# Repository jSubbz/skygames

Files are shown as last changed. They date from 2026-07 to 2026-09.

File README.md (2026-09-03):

# Skygames

Hide and seek played with an FPV drone. A puck gets hidden somewhere in the play
area, the pilot flies out to find it, and a handheld controller gets warmer or
colder (more frequent beeps/less frequent beeps) as the drone closes in.

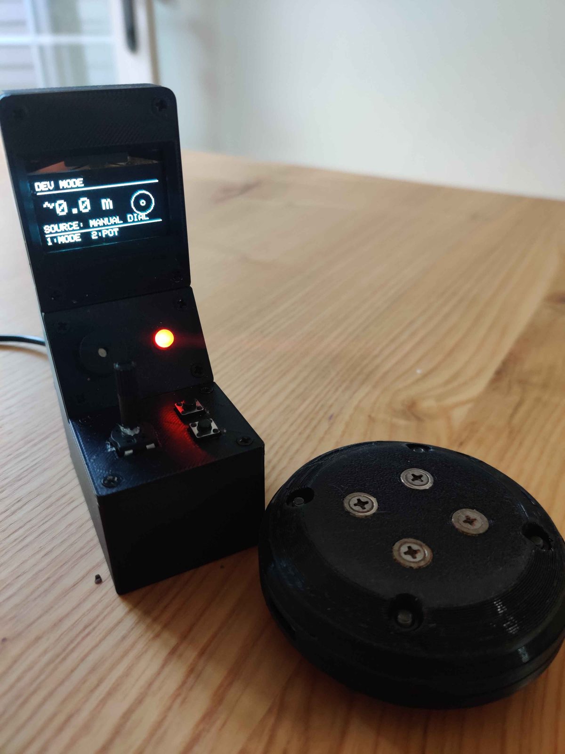
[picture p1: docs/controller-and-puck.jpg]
The controller and the puck. The controller is a printed hinged case with an OLED reading "DEV MODE", a lit red LED, two buttons and a dial; the puck is a black printed disc.


## How the game works

Three boards, one job each.

The **puck** broadcasts a small beacon packet about ten times a second. That is
its only job - it never listens for anything.

The **drone** is the seeker. It hears the beacon, reads the signal strength of
each packet as it arrives, filters it, and buckets the result into NEAR / MID /
FAR / LOST. It relays that zone to the controller about ten times a second.

The **controller** plays the zone back to the pilot on a buzzer and an RGB LED.
No RSSI math happens there.

The sensing sits on the drone on purpose: the drone is the one flying around the
puck, so it has to be the one sensing proximity. A controller sitting still on
the ground would be measuring the pilot's distance instead, which is not the
number anyone wants.

## Signal strength, not GPS

The first design has the puck and the drone both reporting GPS positions, with
the controller working out the distance between them. It does not hold up
indoors: the M10Q cannot keep a fix inside a building, and the system has to
work indoors and out. Signal strength needs no satellites. It is noisy, but it
moves in the right direction, and that is enough for hot-and-cold.

GPS keeps one job - **follow home**, where the drone measures against its own
launch point instead of against the puck. That distance is big enough for GPS to
be good at it, and it is an outdoor feature anyway.

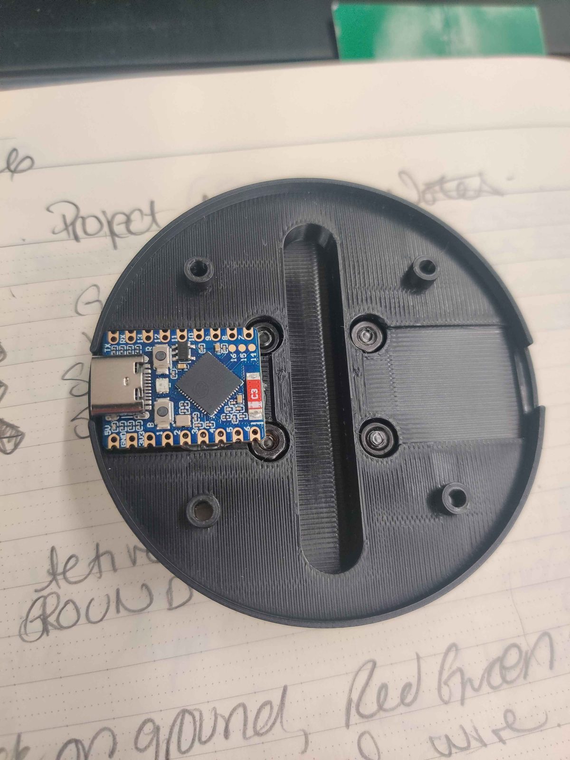
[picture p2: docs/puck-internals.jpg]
The inside of the puck: a printed disc with an ESP32-C3 board screwed to it, sitting on a page of wiring notes.


## Feedback

The buzzer is an active one, so it has a fixed pitch and can only be switched on
and off - it cannot be pitch-shifted by driving the pin at different
frequencies. Proximity is carried by beep rate instead: faster clicks as you get
closer. It runs through PWM rather than a plain digital write so the volume can
be turned down, which it needed.

The RGB LED is PWM-driven too, so colour is a real gradient rather than a few
fixed hues: green close, red far, blending through yellow between, off when the
signal is lost. It blinks in sync with the buzzer.

Two buttons. **Mode** toggles between follow-puck and follow-home. **Pot
toggle** switches the potentiometer dial in and out of the loop - the dial is a
bench override that feeds a manual distance in place of live sensing.

## Repository layout

```
src/controller/        the handheld unit - display, buzzer, RGB LED, buttons
src/esp_now_gps_tx/    the drone - GPS fix, RSSI sensing, relays both
src/puck_gps_tx/       the puck - beacon broadcaster
src/experiments/       bench sketches, one per component (see its README)
models/                FreeCAD enclosures for the puck and the controller
docs/                  photos
```

Those three sketches stand in for eleven. Every component gets proved on its own
first - a sketch that only blinks an LED over the radio, one that only parses
GPS, one that only drives the screen - and the working parts fold into three
programs that talk to each other. The originals stay in `src/experiments/`, both
as a record and because several are still the quickest way to test a board you
have just soldered.

`puck_gps_tx` keeps its name from when the puck still carried GPS. The name is
wrong, but the history is easier to follow with it left alone.

## Hardware

| Part | Board |
|---|---|
| Controller | ESP32-C6 Pico |
| Drone | ESP32-C3 |
| Puck | ESP32-C3 |

| Peripheral | Notes |
|---|---|
| SH1106 OLED | I2C, driven through Adafruit GFX and SH110X |
| M10Q GPS module | UART, parsed with TinyGPS++ |
| Active piezo buzzer | Fixed pitch, so feedback is by rate |
| Common-cathode RGB LED | PWM, continuous green-to-red gradient |
| Momentary pushbuttons | Mode, and the dial override |
| Potentiometer | Bench override for manual distance |
| 18650 cell + TP4056 | Power and USB-C charging |

Controller wiring, confirmed against the built unit:

```
OLED (I2C)        SDA 22, SCL 23
Buttons           mode 2, pot toggle 3
Buzzer            18
RGB LED           19 / 20 / 21
Potentiometer     0
```

On the drone, the GPS module's TX line goes to GPIO20. It is a passive tap - the
sketch passes -1 for its own TX pin, so it can never drive the wire it is
reading.

## Flashing

Arduino IDE with the `esp32` boards package by Espressif, version 3.x. Pick
**ESP32C6 Dev Module** for the controller and **ESP32C3 Dev Module** for the
drone and the puck. Enable *USB CDC On Boot* on all three - these boards have no
USB-to-serial chip, so that is what makes Serial work over the native USB-C
port.

Libraries: **TinyGPSPlus** by Mikal Hart (not the older `TinyGPS`, which has a
different API), **Adafruit GFX**, **Adafruit SH110X**.

All three boards need to be locked to the same WiFi channel - see
`WIFI_CHANNEL` in each sketch. RSSI readings only compare within a channel, and
the link is only reliable when the radios agree on one.

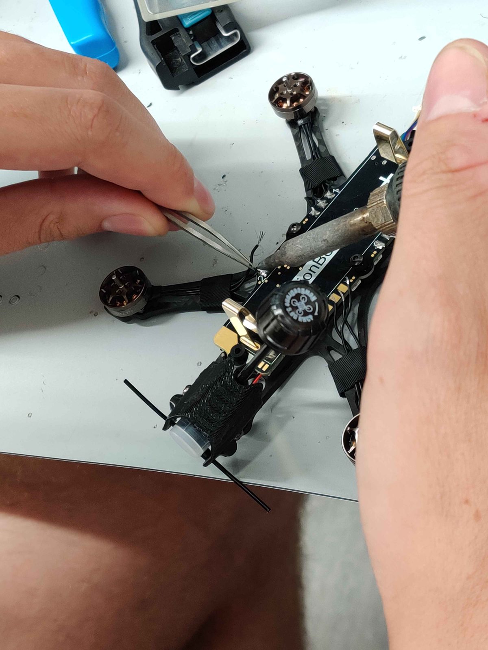
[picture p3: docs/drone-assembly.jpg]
A drone frame being soldered by hand, motors and wiring visible.


## Enclosures

`models/` holds the FreeCAD sources for the puck and controller housings. No
mesh exports yet, so printing one means opening FreeCAD for now.

## Known rough edges

The boards address each other by **broadcast**, not by paired MAC. It works with
no setup, and it also means a board picks up beacons from any other Skygames
puck in range. Each sketch prints its own MAC on boot, so swapping in real peer
addresses is a small change when it matters.

The controller's **screen is a placeholder** - a plain status readout, not a
designed interface. The "set puck" screen in `src/experiments/ui_test` is where
that was heading.

The **potentiometer has a worn track** and jumps on its own occasionally - it
came out of a school kit and has had a previous life. That is why there is a
button to shut the dial out of the loop entirely.

## Next

**More game modes** - capture the flag, push the cart - on the same telemetry
and RSSI foundation. Game logic is centralised on the controller, so a new mode
needs no drone firmware change. That is most of why it is built that way.

**A drone-agnostic mount** around the 1S/18650 power system consumer
micro-drones already use, so the electronics bolt onto a drone somebody already
owns instead of needing a custom build.

**Better-sounding audio cues** for players, so a bare buzzer is not the only
thing to listen to.

**Peer MACs and a designed screen**, both from the rough edges above.

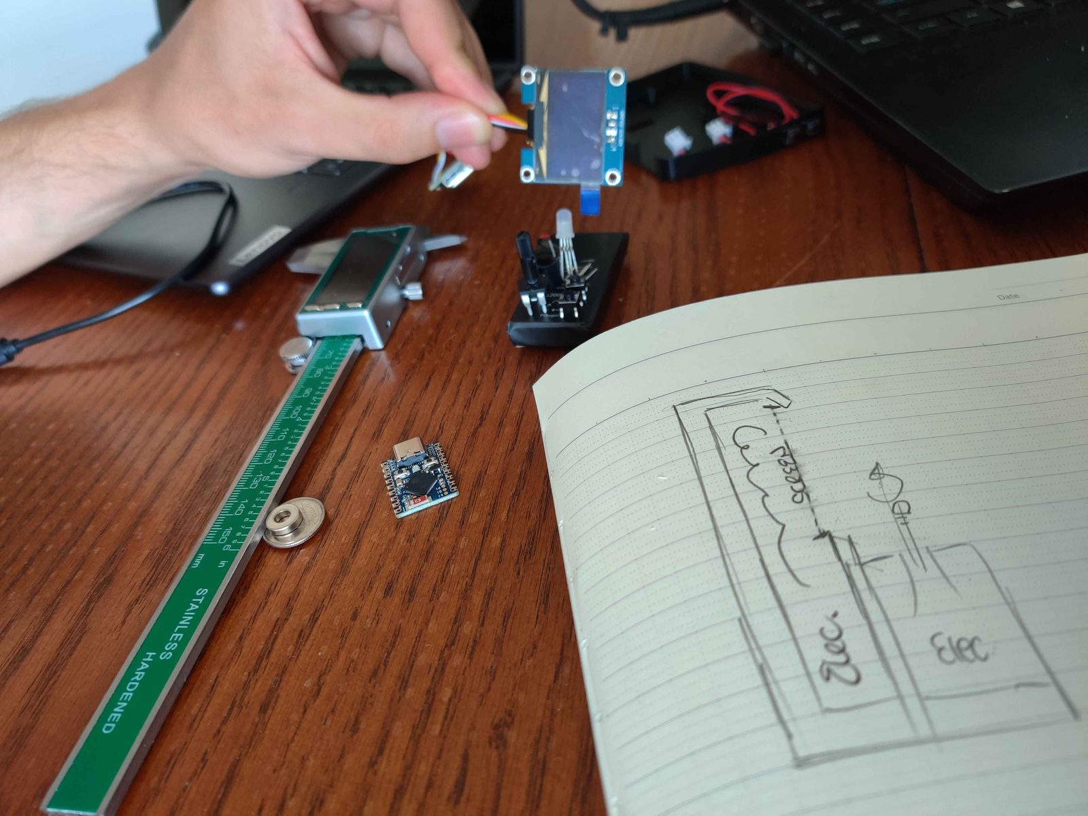
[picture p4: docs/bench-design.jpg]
Early bench work: an OLED, an encoder and a bare ESP32 board on a desk beside a notebook sketch of the controller.


## Credits

Built with Brayden ([@braybuch](https://github.com/braybuch)) for ENL 4003.
Brayden handled hardware selection, bench testing and enclosure work, and wrote
the original proximity finder the whole signal-strength approach comes out of.

## Licence

MIT - see [LICENSE](LICENSE).

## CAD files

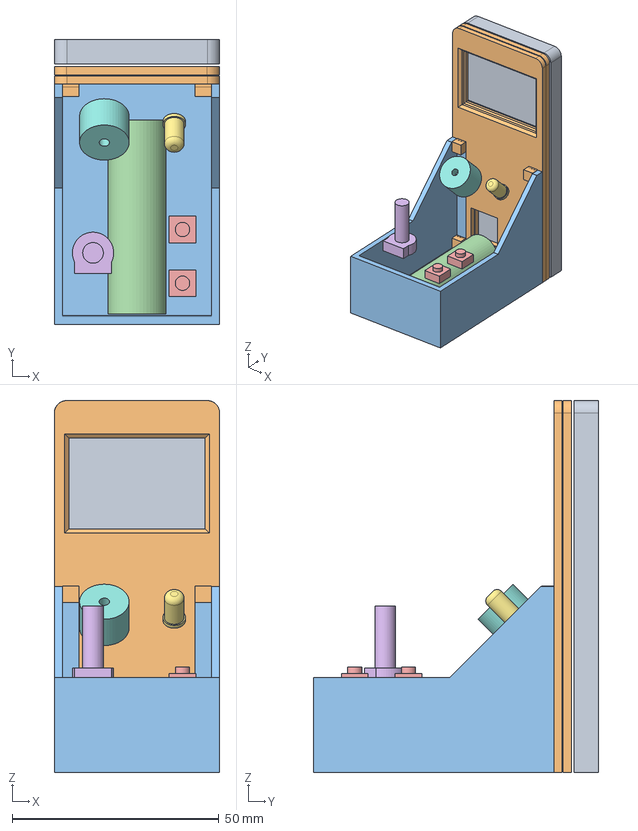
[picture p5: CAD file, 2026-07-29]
models/controller.FCStd
40.0 x 69.0 x 90.0 mm
Upper-Back
Upper-Front x 2
Lower-Bottom x 2
AA
Button x 2
Knob
LED
Beeper
1.3-inch-llc-V3.001

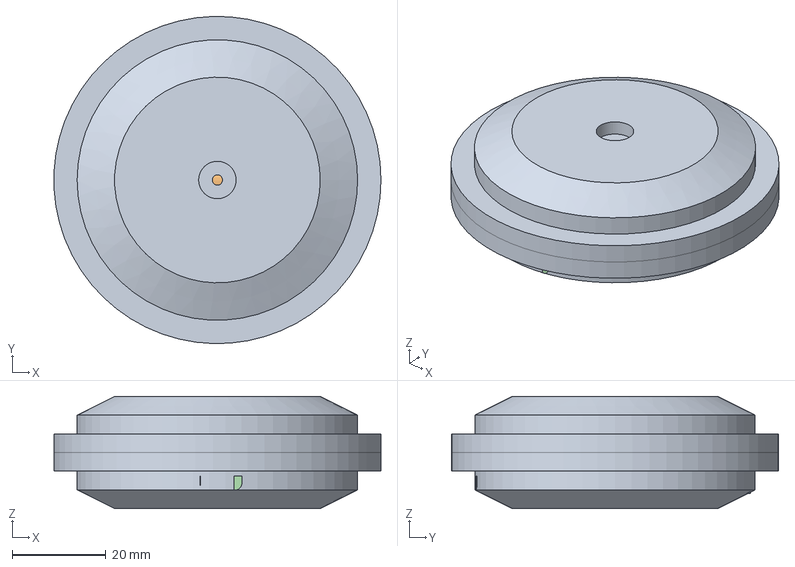
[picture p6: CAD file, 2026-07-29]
models/puck.FCStd
70.0 x 70.0 x 24.0 mm
puck x 2
AAA battery
ESP32S3 Zero
LX-LBC3

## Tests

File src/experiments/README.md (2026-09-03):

# Experiments

Bench sketches from building the system, each one written to prove a single
component or idea on its own before it was allowed near the real thing. None of
them are part of the game; they are kept because they are how the three sketches
in `src/` came to work, and because several are still the quickest way to test a
board you have just soldered.

| Sketch | What it proved |
|---|---|
| `mac-finder` | Prints a board's MAC address. Needed before ESP-NOW can address a specific peer. |
| `tesst` | Blinks the onboard LED. The first thing to run on a board you are not sure is alive. |
| `blinky_tx` / `blinky_rx` | Smallest possible ESP-NOW link: one board makes the other's LED blink. Proves the radio pairing before any payload matters. |
| `hardwaretest` | ESP32-C6 Pico bring-up - every pin on the controller exercised in one sketch. |
| `gps_parse_test` | Reads the GPS module over UART and parses it with TinyGPS++. Passive listener, no radio. |
| `esp_now_display_tx` / `esp_now_display_rx` | Sends an invented, slowly drifting GPS fix to an SH1106 OLED. Let the display and the message format be tested with no GPS lock and no second location. |
| `esp_now_gps_rx` | The display receiver wired to real GPS data rather than the mock. |
| `esp_now_proximity_finder` | Brayden's two-role prototype: one board broadcasts a beacon, the other reads RSSI, filters it and buckets it into NEAR / MID / FAR / LOST. This is the sketch the whole RSSI approach came out of, and both `puck_gps_tx` and the drone's sensing are descended from it. |
| `ui_test` | Standalone rig for the "Set Puck" screen - OLED, two buttons and a rotary encoder, with no radio attached. |

## Flashing any of them

Arduino IDE with the `esp32` boards package by Espressif, version 3.x. Board
depends on the sketch - the ESP32-S3 Zero sketches want **ESP32S3 Dev Module**
with *USB CDC On Boot* enabled, which is what makes Serial work over the native
USB-C port. Individual sketches note their own wiring in the header comment.

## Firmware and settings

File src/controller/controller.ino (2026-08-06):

/*
 * Controller / Receiver - consolidated draft (v4)
 * -------------------------------------------------
 * Replaces the separate blinky_rx / esp_now_display_rx / esp_now_gps_rx
 * drafts with one sketch.
 *
 * Architecture (as of this draft):
 *   Puck  --beacon_t, ~10x/sec-->  Drone
 *   Drone --filters RSSI, classifies NEAR/MID/FAR/LOST zone (same
 *           logic as esp_now_proximity_finder.ino's SEEKER role) -->
 *   Drone --proximity_report_t, ~10x/sec-->  Controller (this board)
 *   Controller drives buzzer/RGB LED off the zone the drone relays. No
 *   RSSI math happens here - the drone is the one flying around the
 *   puck, so it has to be the one sensing proximity; the controller
 *   just plays the result back to the operator.
 *
 *   Drone --struct_message (GPS), ~1x/sec--> Controller, for the
 *   separate FOLLOW HOME feature (drone <-> its own first fix, no
 *   controller GPS). Puck no longer sends GPS - drone<->puck finding
 *   is RSSI-only.
 *
 * Controls (2026-08-06 - button roles changed from earlier drafts):
 *   - Button 1 (MODE): toggles between FOLLOW PUCK and FOLLOW HOME each
 *     press - no longer two separate "set to X" buttons.
 *   - Button 2 (POT TOGGLE): enables/disables the potentiometer dial
 *     override entirely. Added because the dial's known worn-track
 *     jumpiness (see notes further down) could occasionally trip
 *     dialOverrideActive on its own and never let go of live sensing -
 *     this gives a hard way to shut the dial out of the loop while
 *     testing the real puck/drone system.
 *   - Potentiometer dial (only listened to while pot override is
 *     enabled): dev/test override. Turning it feeds a manual distance
 *     into the buzzer/LED instead of live sensing; reverts to live data
 *     automatically 5s after you stop turning it.
 *
 * Screen content is still open (per team discussion) - updateDisplay()
 * below is a plain status readout, not a locked-in UI design. Treat it
 * as a placeholder to swap out once the "SET PUCK" screen concept
 * (ui_test.ino) is settled.
 *
 * WIRE PROTOCOL - three message types travel over ESP-NOW to this board:
 * ------------------------------------------------------------------
 *   struct_message (GPS) - sent ~1x/sec by esp_now_gps_tx.ino (drone
 *   only now). Must match field-for-field:
 *
 *     typedef struct struct_message {
 *       uint8_t deviceId;  // DEVICE_DRONE (0) or DEVICE_PUCK (1)
 *       bool fixValid;
 *       double lat;
 *       double lon;
 *       uint8_t sats;
 *     } struct_message;
 *
 *   proximity_report_t (RSSI relay) - sent ~10x/sec by the drone
 *   (esp_now_gps_tx.ino), which does its own RSSI filtering/zone
 *   classification against the puck's beacon. Must match exactly:
 *
 *     typedef struct { float rssi; uint8_t zone; } proximity_report_t;
 *     // zone: 0=NEAR, 1=MID, 2=FAR, 3=LOST
 *
 * The puck's beacon_t (see puck_gps_tx.ino / esp_now_proximity_finder.ino)
 * is NOT received here directly anymore - the drone is the one that
 * listens for it.
 *
 * All radios (controller, drone, puck) should lock to the same fixed
 * WiFi channel (see WIFI_CHANNEL below) for reliable reception.
 *
 * PIN CONFIG - confirmed against real controller wiring (2026-08-05).
 * ------------------------------------------------------------
 * Matches hardwaretest.ino, which is flashed on this board and fully
 * working: OLED on 22/23, buttons on 2/3, buzzer on 18, RGB LED
 * (common cathode) on 19/20/21, potentiometer wiper on GPIO0. The
 * earlier v3 draft's pins (I2C 6/7, buttons 4/5, rotary encoder
 * 2/3/1) were copied from ui_test.ino's separate bench rig and did
 * not match this board - replaced below.
 *
 * BUZZER - confirmed genuinely active (2026-08-05), not a passive
 * piezo. An active buzzer has its own fixed-pitch oscillator and can
 * only be switched on/off - it cannot be pitch-shifted by driving the
 * pin at different frequencies. So zone/distance feedback below is
 * conveyed by beep RATE (how fast it clicks) instead of pitch. Driven
 * via LEDC PWM rather than a plain digitalWrite so BUZZER_VOLUME_PERCENT
 * can turn the volume down (2026-08-05 - full HIGH/LOW drive was too loud).
 *
 * RGB LED (2026-08-06) - also PWM-driven now (not plain on/off), so
 * color is a genuine continuous gradient instead of a handful of fixed
 * hues: green = close, red = far, blending through yellow in between.
 * off = lost/no signal. (Earlier draft had this backwards - red=close -
 * flipped per team direction.) Still blinks in sync with the buzzer's
 * on/off click.
 */

#include <Wire.h>
#include <Adafruit_GFX.h>
#include <Adafruit_SH110X.h>
#include <WiFi.h>
#include <esp_now.h>
#include <esp_wifi.h>
#include <math.h>

// ---- Pin configuration (matches hardwaretest.ino / real wiring) ----
#define I2C_SDA 22                   // OLED SDA
#define I2C_SCL 23                   // OLED SCL
#define POT_PIN 0                    // potentiometer wiper - dev/test dial
#define BUTTON_MODE_PIN 2            // = hardwaretest.ino's BUTTON1_PIN - toggles FOLLOW PUCK/HOME
#define BUTTON_POT_TOGGLE_PIN 3      // = hardwaretest.ino's BUTTON2_PIN - enables/disables the dial
#define BUZZER_PIN 18                // active buzzer - on/off only, no pitch control
#define LED_R 19                     // RGB LED, common cathode
#define LED_G 20
#define LED_B 21

// ---- OLED config (same as esp_now_gps_rx.ino / ui_test.ino) ----
#define SCREEN_WIDTH 128
#define SCREEN_HEIGHT 64
#define OLED_ADDR 0x3C
#define OLED_RESET -1
// 0 = as-is, 2 = flipped 180 - set to whichever reads right-side up in
// your enclosure (bench video 2026-08-05 showed text upside down at 0).
#define DISPLAY_ROTATION 2
Adafruit_SH1106G display(SCREEN_WIDTH, SCREEN_HEIGHT, &Wire, OLED_RESET);

// ---- Radio config - must match esp_now_gps_tx.ino / puck_gps_tx.ino ----
#define WIFI_CHANNEL 1
const uint8_t TX_POWER_QUARTER_DBM = 84; // 84 = 21 dBm (max) - keep identical on all radios

// ---- FOLLOW HOME distance -> beep-rate mapping. Tune once real-world
// distances are known. Buzzer is on/off only (see note above), so
// "getting warmer" is conveyed by faster clicking, not higher pitch. ----
const float DIST_MIN_M = 1.0f;             // at or below this: fastest click ("hot")
const float DIST_MAX_M = 100.0f;           // at or above this: slowest click ("cold")
const uint16_t HOME_CLICK_ON_MS = 90;      // click length, constant across the range
const uint16_t HOME_PERIOD_MIN_MS = 150;   // click period when close
const uint16_t HOME_PERIOD_MAX_MS = 1000;  // click period when far

// ---- Buzzer volume, via PWM duty cycle (see header note - active buzzer,
// full HIGH/LOW drive was reported too loud 2026-08-05). Lower duty =
// lower average voltage = quieter, down to some point where a given
// buzzer stops oscillating altogether - stay well above that floor. ----
const int BUZZER_PWM_FREQ_HZ = 20000;      // carrier above hearing range - no PWM whine
const int BUZZER_PWM_RESOLUTION_BITS = 8;  // 0-255 duty steps
const uint8_t BUZZER_VOLUME_PERCENT = 65;  // tune this one knob if it needs to go up/down
const uint8_t BUZZER_DUTY_ON = (uint8_t)(BUZZER_VOLUME_PERCENT * 255 / 100);

// ---- RGB LED gradient config (2026-08-06). Color is continuous now, not
// bucketed - FOLLOW HOME/dial reuse DIST_MIN_M/DIST_MAX_M directly as the
// gradient's near/far ends. FOLLOW PUCK doesn't get a meters value from
// the drone, so it mirrors the RSSI thresholds instead (cosmetic only -
// not wire-protocol critical, but keep roughly in sync with
// esp_now_gps_tx.ino's RSSI_NEAR/RSSI_FAR if those get retuned). ----
const float RSSI_NEAR_MIRROR_DBM = -55.0f; // at/stronger than this: full green
const float RSSI_FAR_MIRROR_DBM  = -82.0f; // at/weaker than this: full red

// ---- Manual override (potentiometer) config ----
const int POT_ADC_MIN = 0;
const int POT_ADC_MAX = 4095;                // ESP32 12-bit ADC
const int POT_MOVE_THRESHOLD = 25;           // ignore ADC jitter smaller than this
const float POT_SMOOTHING_ALPHA = 0.25f;     // 0-1, lower = smoother. Without this, raw ADC
                                              // noise fed straight into periodMs every loop and
                                              // made the buzzer crackle instead of click cleanly
                                              // while turning fast (seen in 2026-08-05 bench video)
const float OVERRIDE_DIST_MIN_M = 0.0f;
const float OVERRIDE_DIST_MAX_M = DIST_MAX_M;
const unsigned long DIAL_OVERRIDE_TIMEOUT_MS = 5000; // revert to live sensing this long after last turn

// ---- GPS freshness (drone only, for FOLLOW HOME) ----
const unsigned long GPS_TIMEOUT_MS = 5000;

// ---- Proximity relay freshness (drone's RSSI report, for FOLLOW PUCK) ----
const unsigned long PROXIMITY_REPORT_TIMEOUT_MS = 800;

// =====================================================================
// GPS wire protocol (drone only - see esp_now_gps_tx.ino)
// =====================================================================
enum DeviceId : uint8_t { DEVICE_DRONE = 0, DEVICE_PUCK = 1 };

typedef struct struct_message {
  uint8_t deviceId;
  bool fixValid;
  double lat;
  double lon;
  uint8_t sats;
} struct_message;

struct_message droneMsg = { DEVICE_DRONE, false, 0, 0, 0 };
unsigned long droneLastSeen = 0;

// ---- Home point: captured once from the drone's first valid fix ----
bool homeSet = false;
double homeLat = 0.0;
double homeLon = 0.0;

// =====================================================================
// RSSI proximity relay (drone senses, this board just consumes it)
// =====================================================================
typedef struct {
  float rssi;
  uint8_t zone;
} proximity_report_t;

enum PuckZone { ZONE_NEAR = 0, ZONE_MID = 1, ZONE_FAR = 2, ZONE_LOST = 3 };
const char *zoneNames[] = { "NEAR", "MID", "FAR", "LOST" };

// on/off click timing only - no freq field, since the buzzer can't be
// pitch-shifted. Must still *feel* like the beep feel
// esp_now_proximity_finder.ino uses (rapid when close, slow when far).
struct BeepPattern {
  uint16_t onMs;       // how long the buzzer sounds within each cycle
  uint16_t periodMs;   // full cycle length (on + off); 0 = silent
};
BeepPattern zonePatterns[4] = {
  { 110, 150 },    // NEAR - rapid, almost continuous
  { 120, 400 },    // MID  - moderate beeping
  { 150, 1000 },   // FAR  - slow beeps
  { 0,   0    }    // LOST - silent
};

// PWM intensities (0-255 per channel) now, not on/off bools - lets the
// LED show a real blended color instead of one of 8 fixed hues.
struct RgbColor { uint8_t r, g, b; };
const RgbColor COLOR_OFF = { 0, 0, 0 };

// All struct types live up here, before ANY function definition (even
// ones like gradientColor() right below that don't use these two) - the
// Arduino IDE hoists auto-generated prototypes for every function as one
// block, inserted at the position of the FIRST function definition in the
// file. Whatever that first function ends up being, every type used by
// ANY function's signature has to already be defined above it, or you
// get "does not name a type" (bit us twice now - 2026-08-05, 2026-08-06 -
// each time a new function got added earlier in the file than the last
// one). Keeping every struct in one block up front avoids this for good.
struct AvState {
  BeepPattern pattern;
  RgbColor color;
};

struct DebouncedButton {
  uint8_t pin;
  bool lastReading;
  bool stableState;
  unsigned long lastChangeMs;
  DebouncedButton(uint8_t p) : pin(p), lastReading(HIGH), stableState(HIGH), lastChangeMs(0) {}
};

// t=0 -> full green (close), t=1 -> full red (far), blending through
// yellow at t=0.5. Caller is responsible for mapping their real-world
// value (meters or RSSI) onto this normalized 0..1 range first.
RgbColor gradientColor(float t) {
  t = constrain(t, 0.0f, 1.0f);
  uint8_t r, g;
  if (t < 0.5f) {
    r = (uint8_t)(t * 2.0f * 255.0f);
    g = 255;
  } else {
    r = 255;
    g = (uint8_t)((1.0f - t) * 2.0f * 255.0f);
  }
  return { r, g, 0 };
}

float rssiToGradientT(float rssiDbm) {
  float clamped = constrain(rssiDbm, RSSI_FAR_MIRROR_DBM, RSSI_NEAR_MIRROR_DBM);
  // near (less negative) -> t=0, far (more negative) -> t=1
  return (RSSI_NEAR_MIRROR_DBM - clamped) / (RSSI_NEAR_MIRROR_DBM - RSSI_FAR_MIRROR_DBM);
}

float latestRssi = 0;
int puckZone = ZONE_LOST;
unsigned long lastProximityReportMillis = 0;

// =====================================================================
// Mode state
// =====================================================================
enum FollowMode { MODE_FOLLOW_PUCK, MODE_FOLLOW_HOME };
FollowMode currentMode = MODE_FOLLOW_PUCK;

// ---- Debounced buttons (plain momentary press; struct itself is defined
// up top with the other types - see note there) ----
const unsigned long DEBOUNCE_MS = 40;

DebouncedButton modeBtn(BUTTON_MODE_PIN);
DebouncedButton potToggleBtn(BUTTON_POT_TOGGLE_PIN);

// Returns true exactly once, on the press edge (HIGH -> LOW, since INPUT_PULLUP)
bool checkPressed(DebouncedButton &btn) {
  bool reading = digitalRead(btn.pin);
  if (reading != btn.lastReading) {
    btn.lastChangeMs = millis();
    btn.lastReading = reading;
  }
  bool pressedEdge = false;
  if (millis() - btn.lastChangeMs > DEBOUNCE_MS && reading != btn.stableState) {
    bool wasHigh = (btn.stableState == HIGH);
    btn.stableState = reading;
    if (wasHigh && reading == LOW) pressedEdge = true;
  }
  return pressedEdge;
}

// ---- Manual override (potentiometer, absolute reading - no encoder on
// this board). Turning the dial is detected as "reading moved more than
// jitter allows"; the override then tracks the dial's absolute position
// live, and hands control back to live sensing 5s after it stops moving.
// Button 2 (BUTTON_POT_TOGGLE_PIN) can shut this whole thing off - see
// potOverrideEnabled below - since the pot's worn track (further down)
// could occasionally fake a "touch" and hijack control on its own. ----
bool potOverrideEnabled = true; // toggled by Button 2 - see loop()
bool dialOverrideActive = false;
unsigned long lastDialMoveMs = 0;
float overrideDistanceM = 15.0f;
int lastPotReading = -1;
float smoothedPot = -1.0f;

// Real potentiometers/wiring rarely hit the full theoretical 0-4095 ADC
// swing POT_ADC_MIN/MAX assume - mapping against a range the pot can't
// actually reach compresses the usable output down to a fraction of
// OVERRIDE_DIST_MAX_M (this is why it only felt like ~1-2m of travel).
// So instead of trusting POT_ADC_MIN/MAX, track the widest raw range
// actually seen and map against that - a couple of full turns end-to-end
// after boot and it self-calibrates to whatever this pot really does.
int potObservedMin = POT_ADC_MAX;
int potObservedMax = POT_ADC_MIN;

unsigned long lastDialDebugMs = 0;
const unsigned long DIAL_DEBUG_INTERVAL_MS = 500; // Serial visibility while calibrating

// Median-of-N glitch filter, applied before anything else touches the
// reading. Bench test (2026-08-05) showed both physical end-stops read
// cleanly but the middle of the travel would suddenly jump to an
// unrelated value (e.g. 14m -> 35m -> 41m -> 14m while turning one way)
// - classic symptom of a worn/dirty spot on the pot's resistive track.
// A median rejects a single bad sample outright instead of just
// dampening it like the EMA below does; the EMA still runs after this
// for general smoothness. If glitches persist even with this in place,
// it's likely a real dead spot on the track - try working the dial back
// and forth across its full range repeatedly (can wipe a dirty contact
// clean), or swap the pot if it keeps happening.
const int POT_MEDIAN_WINDOW = 5; // odd, so there's always a clean middle value
int potHistory[POT_MEDIAN_WINDOW];
int potHistoryCount = 0;
int potHistoryIdx = 0;

int medianOfPotHistory() {
  int sorted[POT_MEDIAN_WINDOW];
  int n = potHistoryCount;
  memcpy(sorted, potHistory, n * sizeof(int));
  for (int i = 1; i < n; i++) {
    int key = sorted[i];
    int j = i - 1;
    while (j >= 0 && sorted[j] > key) {
      sorted[j + 1] = sorted[j];
      j--;
    }
    sorted[j + 1] = key;
  }
  return sorted[n / 2];
}

float floatMap(float x, float inMin, float inMax, float outMin, float outMax) {
  return (x - inMin) * (outMax - outMin) / (inMax - inMin) + outMin;
}

void updateManualOverride() {
  if (!potOverrideEnabled) {
    dialOverrideActive = false; // force live sensing while the dial is switched off
    return;                     // don't even read the pot - keeps it fully out of the loop
  }

  int rawPot = analogRead(POT_PIN);
  potHistory[potHistoryIdx] = rawPot;
  potHistoryIdx = (potHistoryIdx + 1) % POT_MEDIAN_WINDOW;
  if (potHistoryCount < POT_MEDIAN_WINDOW) potHistoryCount++;
  int pot = medianOfPotHistory(); // de-glitched reading - use this below, not rawPot

  if (lastPotReading < 0) lastPotReading = pot;   // first read - nothing to compare yet
  if (smoothedPot < 0) smoothedPot = pot;         // seed the filter

  // Movement detection uses the de-glitched (median) reading too now, so a
  // single bad sample can't falsely trigger/extend the override.
  if (abs(pot - lastPotReading) > POT_MOVE_THRESHOLD) {
    dialOverrideActive = true;
    lastDialMoveMs = millis();
  }
  lastPotReading = pot;

  if (pot < potObservedMin) potObservedMin = pot;
  if (pot > potObservedMax) potObservedMax = pot;

  // But the value that actually drives periodMs is smoothed - see
  // POT_SMOOTHING_ALPHA above for why.
  smoothedPot = POT_SMOOTHING_ALPHA * pot + (1.0f - POT_SMOOTHING_ALPHA) * smoothedPot;

  if (dialOverrideActive) {
    int rangeMax = max(potObservedMax, potObservedMin + 1); // guard div-by-zero pre-calibration
    overrideDistanceM = floatMap(smoothedPot, potObservedMin, rangeMax,
                                  OVERRIDE_DIST_MIN_M, OVERRIDE_DIST_MAX_M);
    if (millis() - lastDialMoveMs > DIAL_OVERRIDE_TIMEOUT_MS) {
      dialOverrideActive = false; // untouched long enough - hand control back to live sensing
    }

    if (millis() - lastDialDebugMs >= DIAL_DEBUG_INTERVAL_MS) {
      lastDialDebugMs = millis();
      Serial.printf("DIAL raw=%d  med=%d  observed=[%d,%d]  dist=%.1fm\n",
                     rawPot, pot, potObservedMin, potObservedMax, overrideDistanceM);
    }
  }
}

// =====================================================================
// FOLLOW HOME distance math
// =====================================================================
double haversineMeters(double lat1, double lon1, double lat2, double lon2) {
  const double R = 6371000.0; // meters
  double dLat = radians(lat2 - lat1);
  double dLon = radians(lon2 - lon1);
  double a = sin(dLat / 2) * sin(dLat / 2) +
             cos(radians(lat1)) * cos(radians(lat2)) *
             sin(dLon / 2) * sin(dLon / 2);
  double c = 2 * atan2(sqrt(a), sqrt(1 - a));
  return R * c;
}

uint16_t distanceToPeriodMs(float distM) {
  float clamped = constrain(distM, DIST_MIN_M, DIST_MAX_M);
  return (uint16_t)floatMap(clamped, DIST_MIN_M, DIST_MAX_M, HOME_PERIOD_MIN_MS, HOME_PERIOD_MAX_MS);
}

RgbColor homeDistanceColor(float distM) {
  float clamped = constrain(distM, DIST_MIN_M, DIST_MAX_M);
  float t = (clamped - DIST_MIN_M) / (DIST_MAX_M - DIST_MIN_M); // 0=close/green, 1=far/red
  return gradientColor(t);
}

// For the OLED - not authoritative for audio (see currentAvState)
bool activeDistanceValid = false;
float activeDistanceM = 0.0f;

// Single source of truth for "what should the buzzer/LED be doing right
// now." Every mode (RSSI relay, home, manual override) funnels through
// here so updateBuzzerAndLed() only ever has to deal with one state.
AvState currentAvState() {
  unsigned long now = millis();

  if (dialOverrideActive) {
    activeDistanceValid = true;
    activeDistanceM = overrideDistanceM;
    BeepPattern p = { HOME_CLICK_ON_MS, distanceToPeriodMs(overrideDistanceM) };
    return { p, homeDistanceColor(overrideDistanceM) };
  }

  if (currentMode == MODE_FOLLOW_HOME) {
    bool droneFresh = droneMsg.fixValid && (now - droneLastSeen < GPS_TIMEOUT_MS);
    if (droneFresh && homeSet) {
      activeDistanceM = (float)haversineMeters(droneMsg.lat, droneMsg.lon, homeLat, homeLon);
      activeDistanceValid = true;
      BeepPattern p = { HOME_CLICK_ON_MS, distanceToPeriodMs(activeDistanceM) };
      return { p, homeDistanceColor(activeDistanceM) };
    }
    activeDistanceValid = false;
    return { { 0, 0 }, COLOR_OFF };
  }

  // MODE_FOLLOW_PUCK - driven by the drone's relayed RSSI zone (beep rate,
  // still discrete/bucketed - fine, it doesn't need to be continuous) and
  // the raw relayed RSSI value (LED color - continuous gradient).
  activeDistanceValid = false;
  bool reportFresh = (now - lastProximityReportMillis) <= PROXIMITY_REPORT_TIMEOUT_MS;
  int effectiveZone = reportFresh ? puckZone : ZONE_LOST;
  RgbColor puckColor = (effectiveZone == ZONE_LOST) ? COLOR_OFF
                                                     : gradientColor(rssiToGradientT(latestRssi));
  return { zonePatterns[effectiveZone], puckColor };
}

// =====================================================================
// Buzzer + RGB LED, driven from one shared on/off cycle so the LED is
// a color-coded mirror of the buzzer's click. Non-blocking.
// =====================================================================
void setLed(const RgbColor &c) {
  ledcWrite(LED_R, c.r);
  ledcWrite(LED_G, c.g);
  ledcWrite(LED_B, c.b);
}
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
void loop() {
  if (checkPressed(modeBtn)) {
    currentMode = (currentMode == MODE_FOLLOW_PUCK) ? MODE_FOLLOW_HOME : MODE_FOLLOW_PUCK;
  }
  if (checkPressed(potToggleBtn)) {
    potOverrideEnabled = !potOverrideEnabled;
    Serial.printf("Pot override %s\n", potOverrideEnabled ? "ENABLED" : "DISABLED");
  }

  updateManualOverride();

  AvState state = currentAvState();
  updateBuzzerAndLed(state);

  updateDisplay();
}

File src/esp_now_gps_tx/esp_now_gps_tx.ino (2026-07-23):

/*
 * DRONE - ESP32-C3 GPS UART Read + TinyGPS++ Parse -> ESP-NOW TX
 * -----------------------------------------------------------------
 * Two jobs, both over ESP-NOW to the controller:
 *
 *   1. Reports its own GPS fix (~1x/sec) so the controller can run
 *      the FOLLOW HOME distance math (drone <-> captured launch point).
 *   2. Is the actual "seeker" for puck-finding: listens for the
 *      puck's RSSI beacon (beacon_t, ~10x/sec), filters + classifies
 *      it into a NEAR/MID/FAR/LOST zone (same logic as Brayden's
 *      esp_now_proximity_finder.ino SEEKER role), and relays that
 *      zone + filtered RSSI to the controller (~10x/sec) as a
 *      proximity_report_t. The controller just plays the corresponding
 *      beep pattern - it doesn't do any RSSI math itself. This is the
 *      drone<->puck link players actually use to find the puck; GPS
 *      is not part of that path anymore.
 *
 * PASSIVE LISTENER (GPS UART): TX pin is passed as -1, never drives
 * the tapped wire.
 *
 * Wiring:
 *   GPS TXD (tapped wire) -> ESP32 GPIO20 (RX only)
 *   GND                   -> ESP32 GND
 *
 * Library needed: TinyGPS++ (search "TinyGPSPlus" by Mikal Hart
 * in the Arduino Library Manager - NOT the old "TinyGPS" library,
 * which has a different API).
 *
 * Update rxMac[] below with the controller's real MAC address once
 * you know it (controller.ino prints its own MAC to Serial on boot).
 * 0xFF broadcast works for now without any pairing - note this means
 * this sketch will also pick up broadcast beacons from ANY nearby
 * puck, not just yours, until you swap in a real peer MAC.
 *
 * WIRE PROTOCOL - all three must match field-for-field across sketches:
 *   struct_message     - controller.ino, puck_gps_tx.ino (unused there
 *                         now, but the type is still shared)
 *   beacon_t            - puck_gps_tx.ino (sender), classified here
 *   proximity_report_t   - controller.ino (receiver)
 *
 * Fixed WiFi channel below must match controller.ino and
 * puck_gps_tx.ino so all three radios are reliably on the same
 * channel and RSSI stays comparable.
 */

#include <Arduino.h>
#include <TinyGPS++.h>
#include <WiFi.h>
#include <esp_now.h>
#include <esp_wifi.h>

#define GPS_RX_PIN 20
#define GPS_BAUD   115200

#define WIFI_CHANNEL 1
const uint8_t TX_POWER_QUARTER_DBM = 84; // 84 = 21 dBm (max) - keep identical on all radios

const uint32_t GPS_SEND_INTERVAL_MS       = 1000; // struct_message, for FOLLOW HOME
const uint32_t PROXIMITY_SEND_INTERVAL_MS = 100;   // proximity_report_t, to controller

HardwareSerial GPSSerial(1);
TinyGPSPlus gps;

// ---- GPS struct (drone's own fix, for FOLLOW HOME) ----
// Must match controller.ino / puck_gps_tx.ino exactly
enum DeviceId : uint8_t { DEVICE_DRONE = 0, DEVICE_PUCK = 1 };

typedef struct struct_message {
  uint8_t deviceId;
  bool fixValid;
  double lat;
  double lon;
  uint8_t sats;
} struct_message;

struct_message outgoingGpsMsg = { DEVICE_DRONE, false, 0, 0, 0 };

// ---- RSSI beacon from the puck ----
// Must match puck_gps_tx.ino / controller.ino exactly
typedef struct {
  uint32_t counter;
} beacon_t;

// ---- Zone classification (same thresholds as esp_now_proximity_finder.ino) ----
// Recalibrate together if these change, or the drone and the standalone
// bench-test sketch will disagree about what counts as "near."
enum PuckZone { ZONE_NEAR = 0, ZONE_MID = 1, ZONE_FAR = 2, ZONE_LOST = 3 };
const int RSSI_NEAR = -55;
const int RSSI_MID  = -70;
const int RSSI_FAR  = -82;
const int RSSI_HYSTERESIS = 4;
const float EMA_ALPHA = 0.15f;
const unsigned long RSSI_SIGNAL_LOST_MS = 800;

float emaRssi = 0;
bool haveFirstRssiReading = false;
unsigned long lastBeaconMillis = 0;
int puckZone = ZONE_LOST;

int classifyZone(float rssi, int prevZone) {
  int nearThresh = RSSI_NEAR, midThresh = RSSI_MID, farThresh = RSSI_FAR;
  // widen the threshold needed to LEAVE the current zone (hysteresis)
  if (prevZone == ZONE_NEAR) nearThresh -= RSSI_HYSTERESIS;
  if (prevZone == ZONE_MID)  midThresh  -= RSSI_HYSTERESIS;
  if (prevZone == ZONE_FAR)  farThresh  -= RSSI_HYSTERESIS;

  if (rssi >= nearThresh) return ZONE_NEAR;
  if (rssi >= midThresh)  return ZONE_MID;
  if (rssi >= farThresh)  return ZONE_FAR;
  return ZONE_LOST;
}

void updatePuckZone() {
  unsigned long now = millis();
  if (haveFirstRssiReading && (now - lastBeaconMillis <= RSSI_SIGNAL_LOST_MS)) {
    puckZone = classifyZone(emaRssi, puckZone);
  } else {
    puckZone = ZONE_LOST;
  }
}

// ---- Relay to controller: this drone's read on the puck's proximity ----
// Must match controller.ino exactly
typedef struct {
  float rssi;
  uint8_t zone;
} proximity_report_t;

// Placeholder broadcast address - swap in the controller's real MAC later
uint8_t rxMac[] = {0xFF, 0xFF, 0xFF, 0xFF, 0xFF, 0xFF};

void onDataSent(const wifi_tx_info_t *tx_info, esp_now_send_status_t status) {
  // Quiet on purpose - fires ~11x/sec (1 GPS + 10 proximity) and would
  // otherwise flood Serial. Uncomment for debugging sends:
  // Serial.println(status == ESP_NOW_SEND_SUCCESS ? "Sent OK" : "Send FAIL");
}

// Incoming beacons from the puck
void onDataRecv(const esp_now_recv_info_t *info, const uint8_t *data, int len) {
  if (len != sizeof(beacon_t)) return; // not a beacon - ignore

  int rssi = info->rx_ctrl->rssi;
  lastBeaconMillis = millis();
  if (!haveFirstRssiReading) {
    emaRssi = rssi;
    haveFirstRssiReading = true;
  } else {
    emaRssi = EMA_ALPHA * rssi + (1.0f - EMA_ALPHA) * emaRssi;
  }
}

void setup() {
  Serial.begin(115200);
  delay(1000);

  Serial.println("Starting GPS parse + ESP-NOW TX/RX (drone)...");

  // -1 for TX pin = RX only, never drives the tapped wire
  GPSSerial.begin(GPS_BAUD, SERIAL_8N1, GPS_RX_PIN, -1);

  WiFi.mode(WIFI_STA);
  WiFi.disconnect();
  esp_wifi_set_channel(WIFI_CHANNEL, WIFI_SECOND_CHAN_NONE);
  esp_wifi_set_max_tx_power(TX_POWER_QUARTER_DBM);

  Serial.print("This device's MAC: ");
  Serial.println(WiFi.macAddress());
  Serial.println("(put this address in the controller's peer list once known)");

  if (esp_now_init() != ESP_OK) {
    Serial.println("Error initializing ESP-NOW");
    return;
  }

  esp_now_register_send_cb(onDataSent);
  esp_now_register_recv_cb(onDataRecv);

  esp_now_peer_info_t peerInfo = {};
  memcpy(peerInfo.peer_addr, rxMac, 6);
  peerInfo.channel = WIFI_CHANNEL;
  peerInfo.encrypt = false;

  if (esp_now_add_peer(&peerInfo) != ESP_OK) {
    Serial.println("Failed to add peer");
    return;
  }
}

unsigned long lastGpsSend = 0;
unsigned long lastProximitySend = 0;
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

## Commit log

2026-07-23 add consolidated controller, move rssi prox sensing to drone with relay to controller
2026-07-29 Added models for the puck and controller
    [controller.FCStd, puck.FCStd]
2026-08-05 controller - real pinss, pwm buzzer vol + rgb gradient, pot mediam/calibration, oled rotation fix
    [controller.ino, hardwaretest.ino, puck_gps_tx.ino]
